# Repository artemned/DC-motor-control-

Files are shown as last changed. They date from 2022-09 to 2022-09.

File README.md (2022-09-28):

# DC-motor-control
### *Hello everyone, I want to share with you my device. This is a DC motor control board. The board is multifunctional and you can verify this by looking at the circuit diagram and the software part. This functionality can be added as needed: connecting sensors, necessary peripherals and adding the software part.*
## *The board looks like :* 
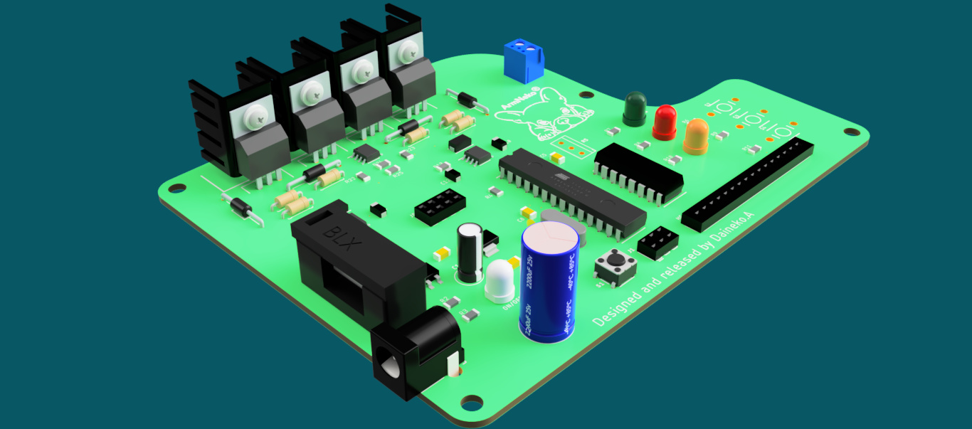
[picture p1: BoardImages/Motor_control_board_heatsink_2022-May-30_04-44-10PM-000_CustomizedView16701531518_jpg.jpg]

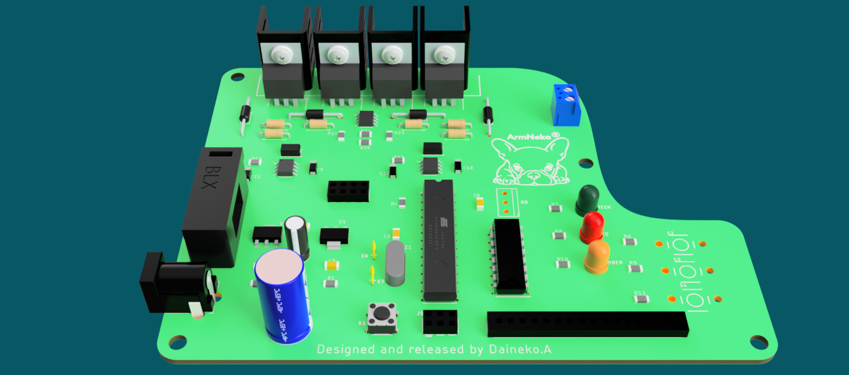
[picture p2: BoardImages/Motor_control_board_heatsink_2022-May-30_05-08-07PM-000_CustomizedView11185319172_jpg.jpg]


### *In the “DriverBoardCode” directory, in addition to the sources and the hex file of the firmware, there is also a zip file of the project, which was created using Microchip Studio.*

### *I use it for my own wood lathe, which is shown in the render in the “BoardImages” directory. The machine is called "Eaglet".*
## *The Eaglet looks like :*
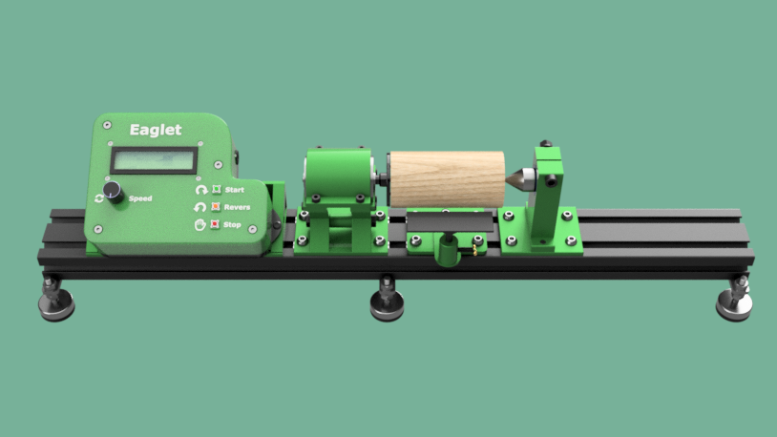
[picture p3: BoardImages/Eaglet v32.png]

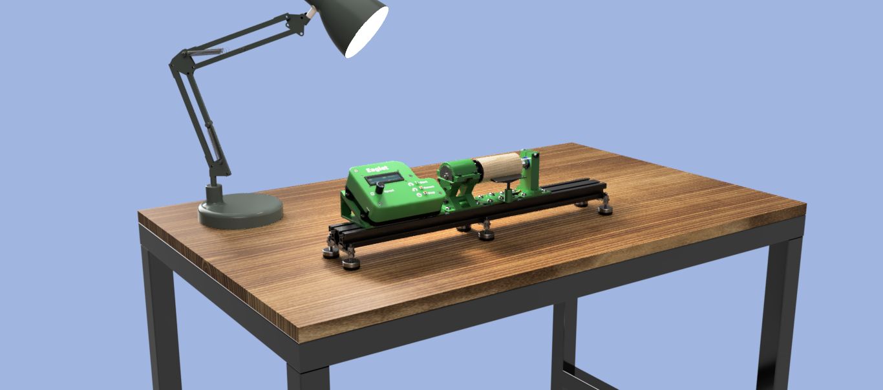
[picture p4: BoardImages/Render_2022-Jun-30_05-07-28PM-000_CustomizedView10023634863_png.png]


### *P.S. Everyone goodness and fresh cookies!*
### *License: [Free license](https://github.com/artemned/DC-motor-control-/blob/main/LICENSE)*
### *Email address for feedback: daineko.a32@mail.ru*

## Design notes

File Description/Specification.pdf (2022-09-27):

Qty | Value | Device | Package | Parts | Description
4 | | LED-3MM-NO_SILK | LED3MM-NS | AMBER, GREEN, ON/OFF, RED | LEDs
1 | 1.0uF | CPOL-EUE2,5-6E | E2,5-6E | C1 | POLARIZED CAPACITOR, European symbol
2 | 3.7uF | CPOL-USSMCA | SMC_A | C11, C12 | POLARIZED CAPACITOR, American symbol
2 | 10uF | C-EUC1206 | C1206 | C2, C3 | CAPACITOR, European symbol
1 | 2200uF | CPOL-EUE5-10.5 | E5-10,5 | C4 | POLARIZED CAPACITOR, European symbol
1 | 10nF | C-EUC1206 | C1206 | C5 | CAPACITOR, European symbol
2 | 22pF | 22PF-PTH-2.54MM-200V-5% | CAP-PTH-2.54 | C6, C7 | 22pF ceramic capacitors
1 | 0.1uF | C-EUC1206 | C1206 | C8,C13 | CAPACITOR, European symbol
2 | 370nF | CPOL-USSMCA | SMC_A | C9, C10 | POLARIZED CAPACITOR, American symbol
2 | MURA110T3G | MURA110T3G | DIOM5226X220N | D1, D2 | Source: Datasheet
4 | MBR0530T1G | MBR0530T1G | SOD3716X135N | D3, D5, D7, D9 | Schottky Rectifier 0.5A 30V SOD-123 ON Semiconductor MBR0530T1G Schottky Diode, 0.5A, 30V, 2-Pin SOD-123
4 | | 1N4007E-E3_73 | DIOAD1405W86L465D235 | D4, D6, D8, D10 | Rectifiers 1.0 Amp 1000 Volt
1 | | SHK20L | SHK20L | F1 | FUSE HOLDER 5 x 20 mm, SH contact, SHH1 Schukat, E1073 Buerklin
1 | LCD16X2 | LCD16X2 | 1X16 | HG1 | LCD 16X2
1 | | ATMEGA328P-PU | DIP794W53P254L3467H457Q28N | IC1 | MICROCHIP - ATMEGA328P-PU. - MICROCONTROLLER MCU, 8 BIT, ATMEGA, 20MHZ, DIP-28
1 | SN74HC595N | SN74HC595N | DIP794W53P254L1930H508Q16N | IC2 | 8-Bit Shift Registers With 3-State Output Registers
2 | IR2101SPBF | IR2101SPBF | SOIC127P600X175-8N | IC3, IC4 | Gate Drivers HI LO SIDE DRVR 600V 130mA 50ns
1 | OPA2376AIDRG4 | OPA2376AIDRG4 | SOIC127P600X175-8N | IC5 | Precision Amplifiers Prec Lo Noise Lo Quies Current Op Amp
1 | | AVR_SPI_PROG_3X2PTH | 2X3 | J1 | AVR ISP 6 Pin
1 | POWER_JACKPTH | POWER_JACKPTH | POWER_JACK_PTH | J2 | Power Jack
1 | | PINHD-2X4 | 2X04 | JP1 | PIN HEADER
1 | DC 24 | Motor | 775 Model | M1 | Motor Spindel
4 | IRFZ34NPBF | IRFZ34NPBF | TO254P469X1042X1967-3P | Q1, Q2, Q3, Q4 | N-channel MOSFET,IRFZ34N 26A 55V
1 | 16MHZ | XTAL/S | QS | QZ1 | CRYSTAL
1 | 200 | R-US_R1206 | R1206 | R1 | RESISTOR, American symbol
2 | 10 | R-US_R1206 | R1206 | R12, R13 | RESISTOR, American symbol
4 | 2 | R-US_0207/7 | 0207/7 | R14, R15, R18, R19 | RESISTOR, American symbol
2 | 50 | R-US_0207/7 | 0207/7 | R16, R17 | RESISTOR, American symbol
1 | 240 | R-US_R1206 | R1206 | R2 | RESISTOR, American symbol
2 | 0,01 | R-EU_R2512 | R2512 | R20, R21 | RESISTOR, European symbol. Yago 0R01 10 mOm
2 | 10 Mom | R-US_R1206 | R1206 | R22, R23 | RESISTOR, American symbol
2 | 95-100 kOm | R-US_R1206 | R1206 | R24, R25 | RESISTOR, American symbol
1 | 11,7 | R-US_R1205 | R1205 | R26 | RESISTOR, American symbol
1 | 2,2khom | R-US_R1206 | R1206 | R3 | RESISTOR, American symbol
1 | 30k | R-US_R1206 | R1206 | R4 | RESISTOR, American symbol
1 | TRIMM_POT | TRIMM_POT | TRIMM_POT | R5
3 | 100 | R-US_R1206 | R1206 | R6, R9, R11 | RESISTOR, American symbol
3 | 220 | R-US_R1206 | R1206 | R7, R8, R10 | RESISTOR, American symbol
1 | SWITCH | MOMENTARY-SWITCH-6.0MM | TACTILE_SWITCH_PTH_6.0MM | S1 | Momentary Switch (Pushbutton) - SPST
3 | | TAC_SWITCH_SPECIAL | TACTILE-SPECIAL_PTH | S2, S3, S4 | Tac Switch
1 | V_REG_317SMD | V_REG_317SMD | SOT223 | U | Voltage Regulator
1 | LM1117GS-5.0 | V_REG_LM1117SOT223 | SOT223 | U1 | Voltage Regulator LM1117
1 | DG340MY" | DG340MY" | 1X02_3.81_SCREWTERM | X1
1 | BZV55C3V6-TP | BAQ33GS08 | smd(mils) | Z | Zener Diodes 3.3V 0.152A
Resistors 22,23,24,25 can be selected deoending on the motor model

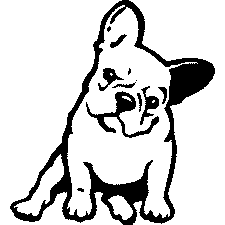
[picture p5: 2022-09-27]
Driver_motor/french`s/franchF.bmp

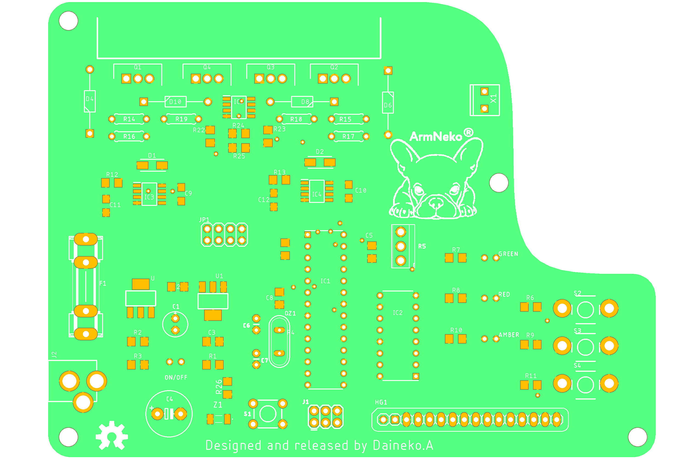
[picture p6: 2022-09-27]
Description/board_top.png

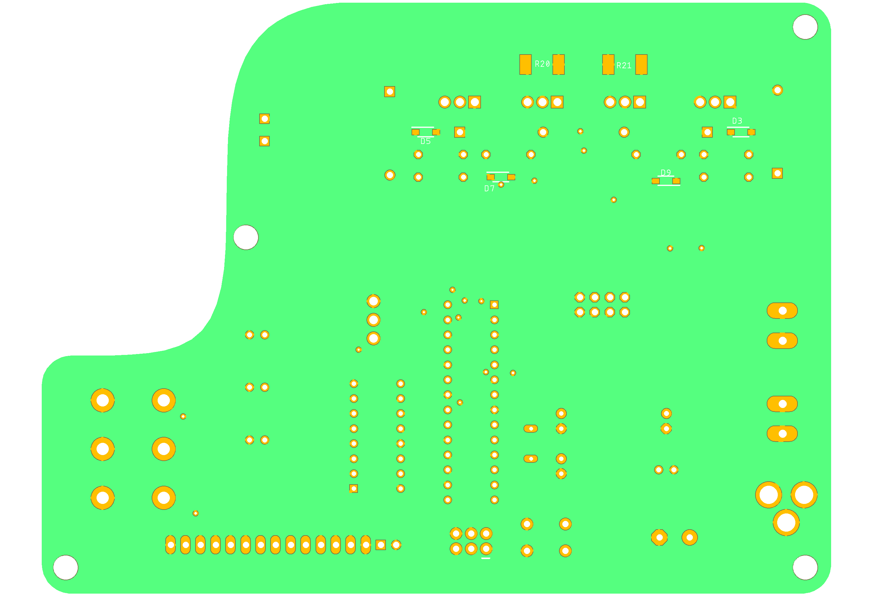
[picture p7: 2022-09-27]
Description/board_bottom.png

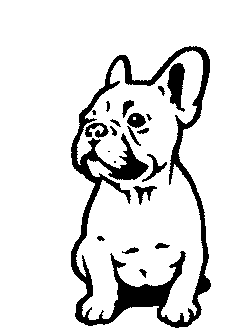
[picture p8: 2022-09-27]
Driver_motor/french`s/franchS.bmp

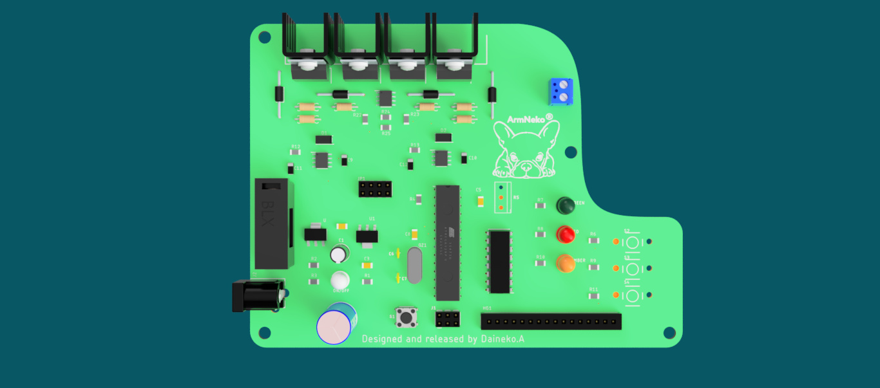
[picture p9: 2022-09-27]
BoardImages/Motor_control_board_heatsink_2022-May-30_05-16-09PM-000_CustomizedView3325845556_jpg.jpg

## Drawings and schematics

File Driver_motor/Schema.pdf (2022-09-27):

A

A

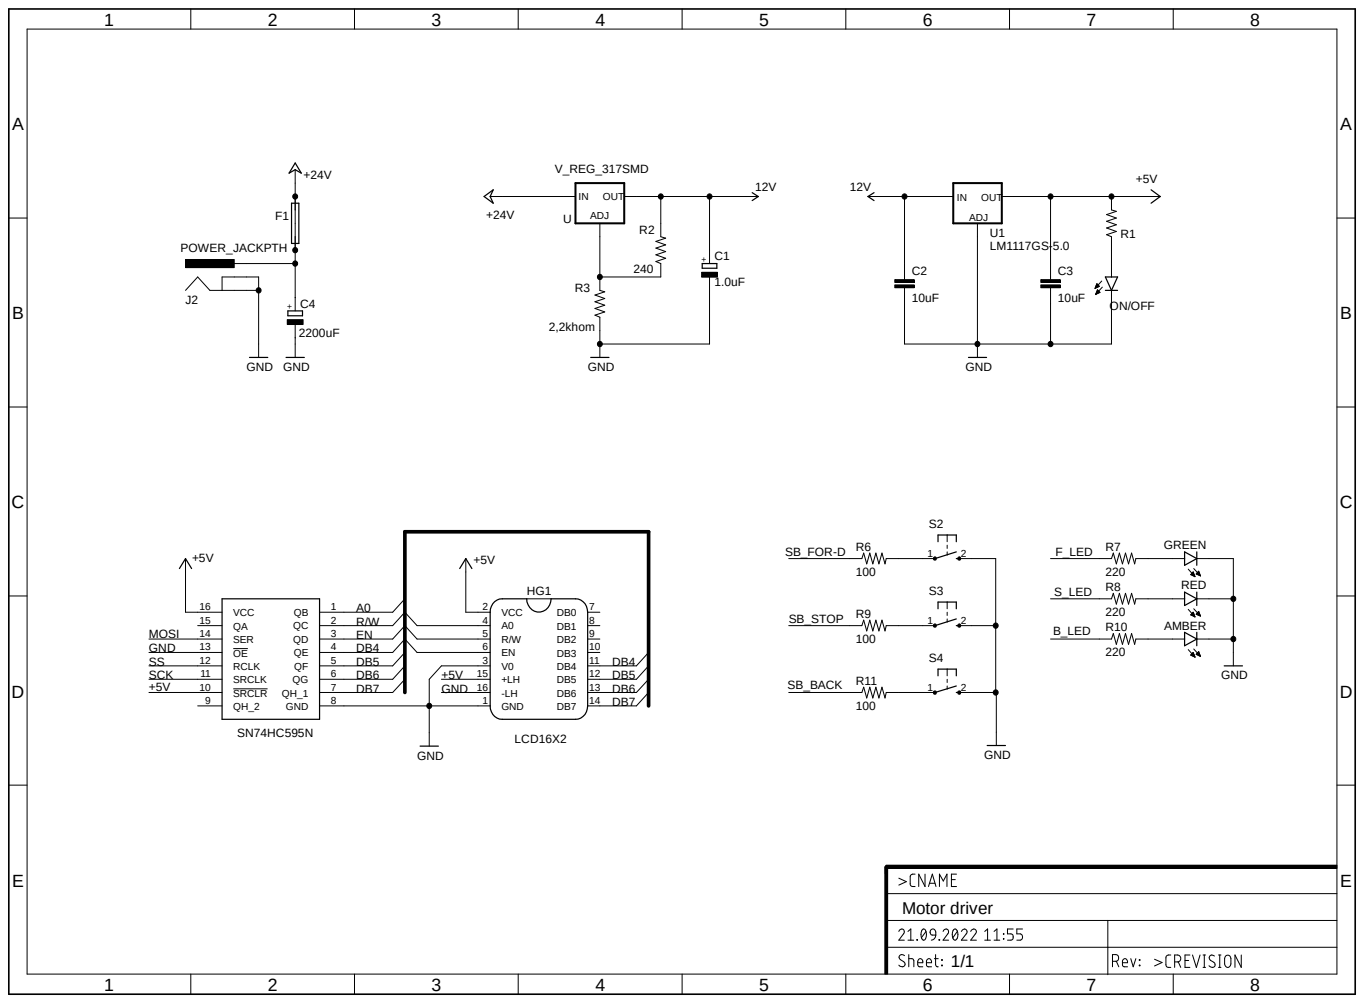
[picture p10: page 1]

5 | 6 | C5

A

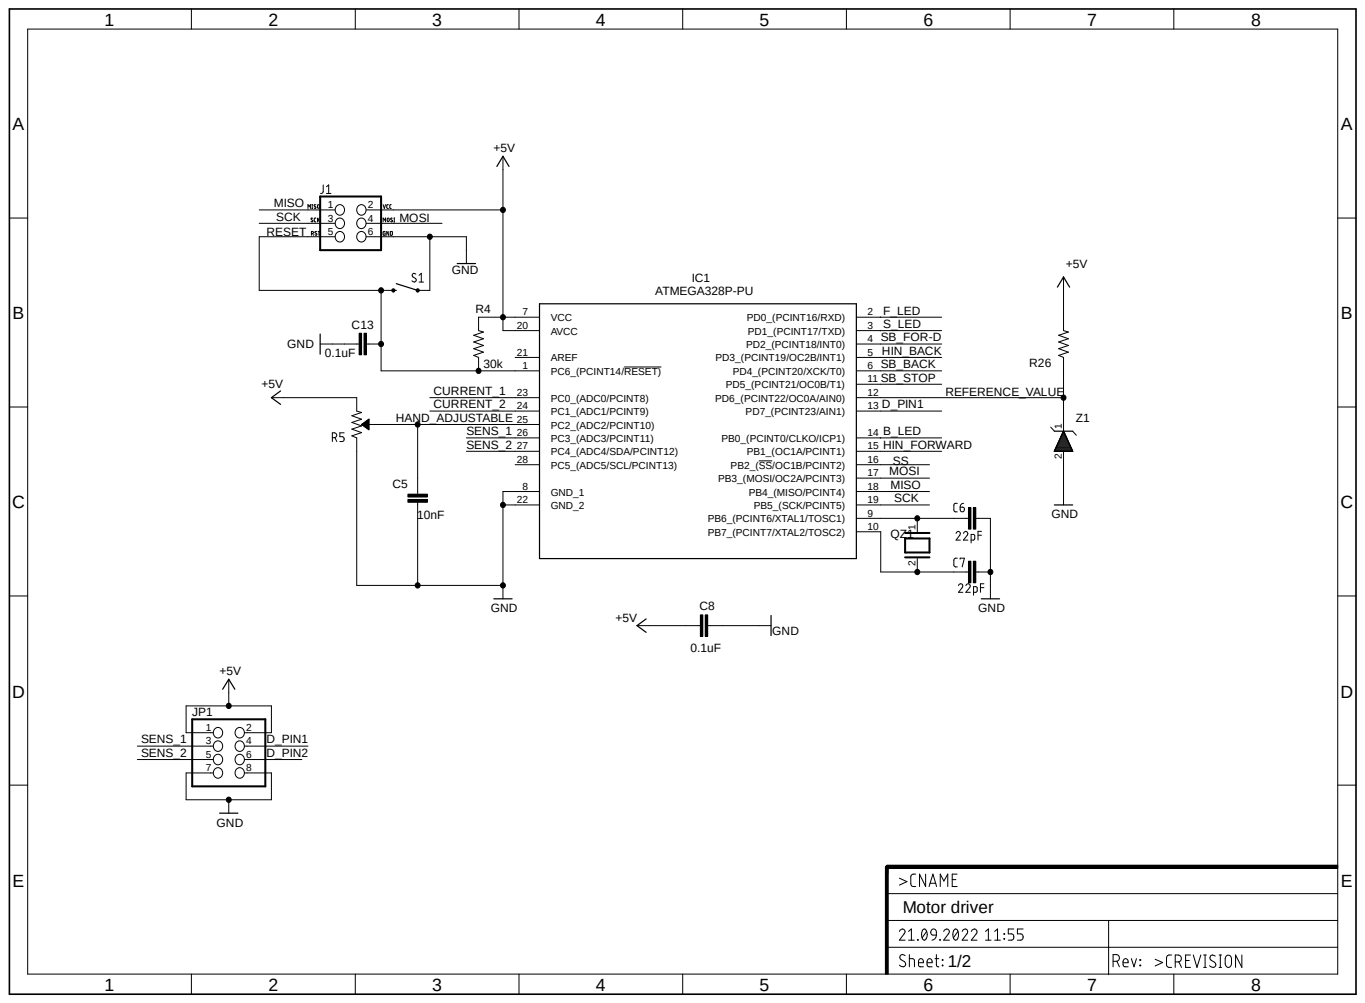
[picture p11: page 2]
GND; ATMEGA328P-PU; PC6_(PCINT14/RESET) 1; PD0_(PCINT16/RXD); PD1_(PCINT17/TXD); PD2_(PCINT18/INT0); PD3_(PCINT19/OC2B/INT1); PD4_(PCINT20/XCK/T0); VCC 7; GND_1 8; PB6_(PCINT6/XTAL1/TOSC1); PB7_(PCINT7/XTAL2/TOSC2); PD5_(PCINT21/OC0B/T1); PD6_(PCINT22/OC0A/AIN0); PD7_(PCINT23/AIN1); PB0_(PCINT0/CLKO/ICP1); PB1_(OC1A/PCINT1); PB2_(SS/OC1B/PCINT2); PB3_(MOSI/OC2A/PCINT3); PB4_(MISO/PCINT4); PB5_(SCK/PCINT5); AVCC 20; AREF 21; GND_2 22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

A

A

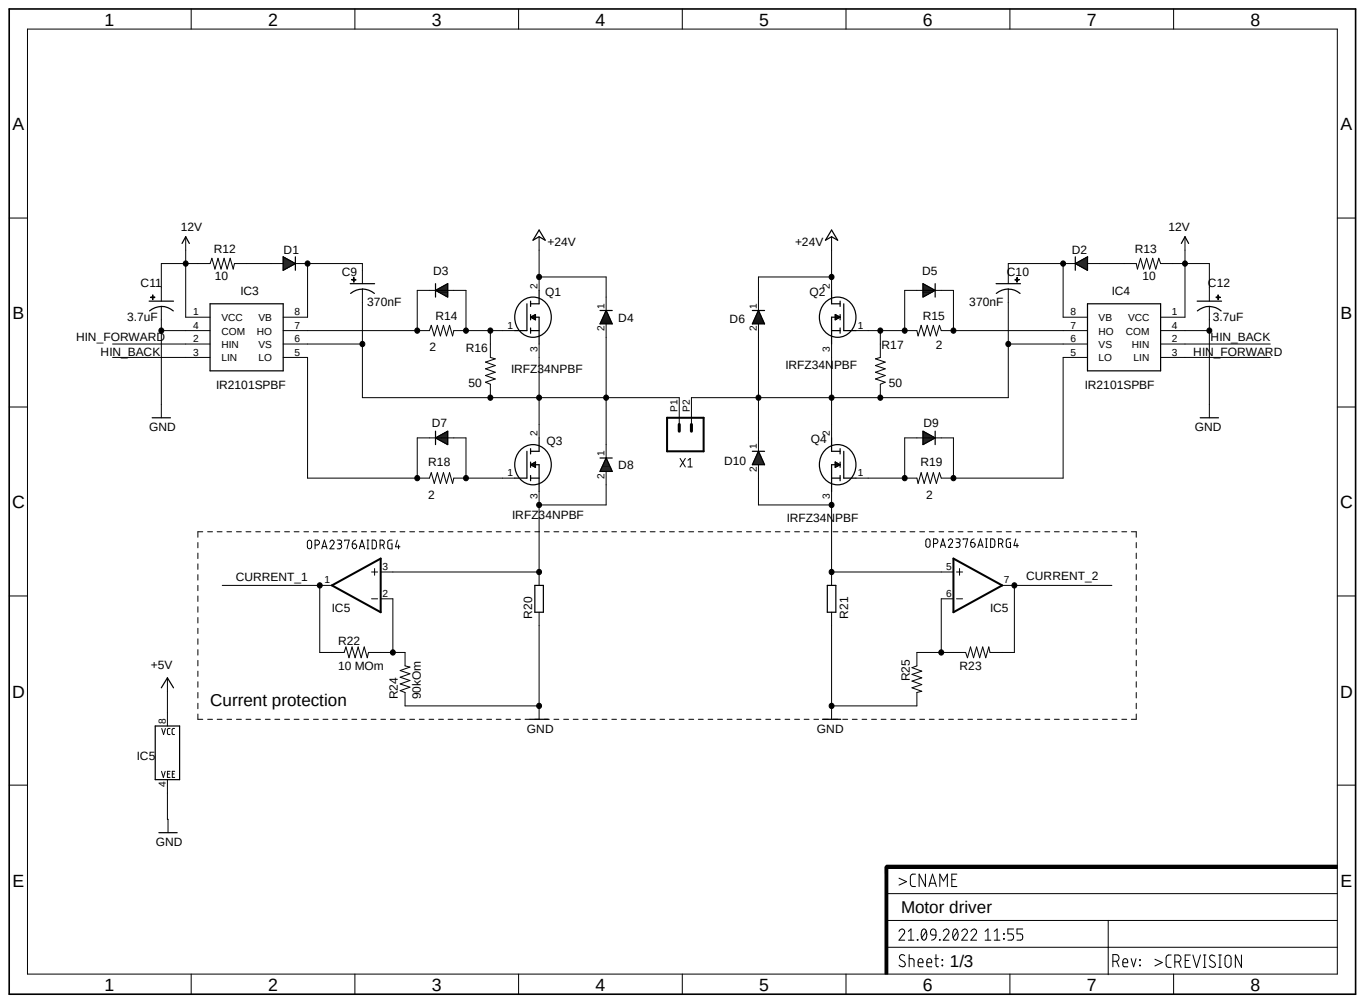
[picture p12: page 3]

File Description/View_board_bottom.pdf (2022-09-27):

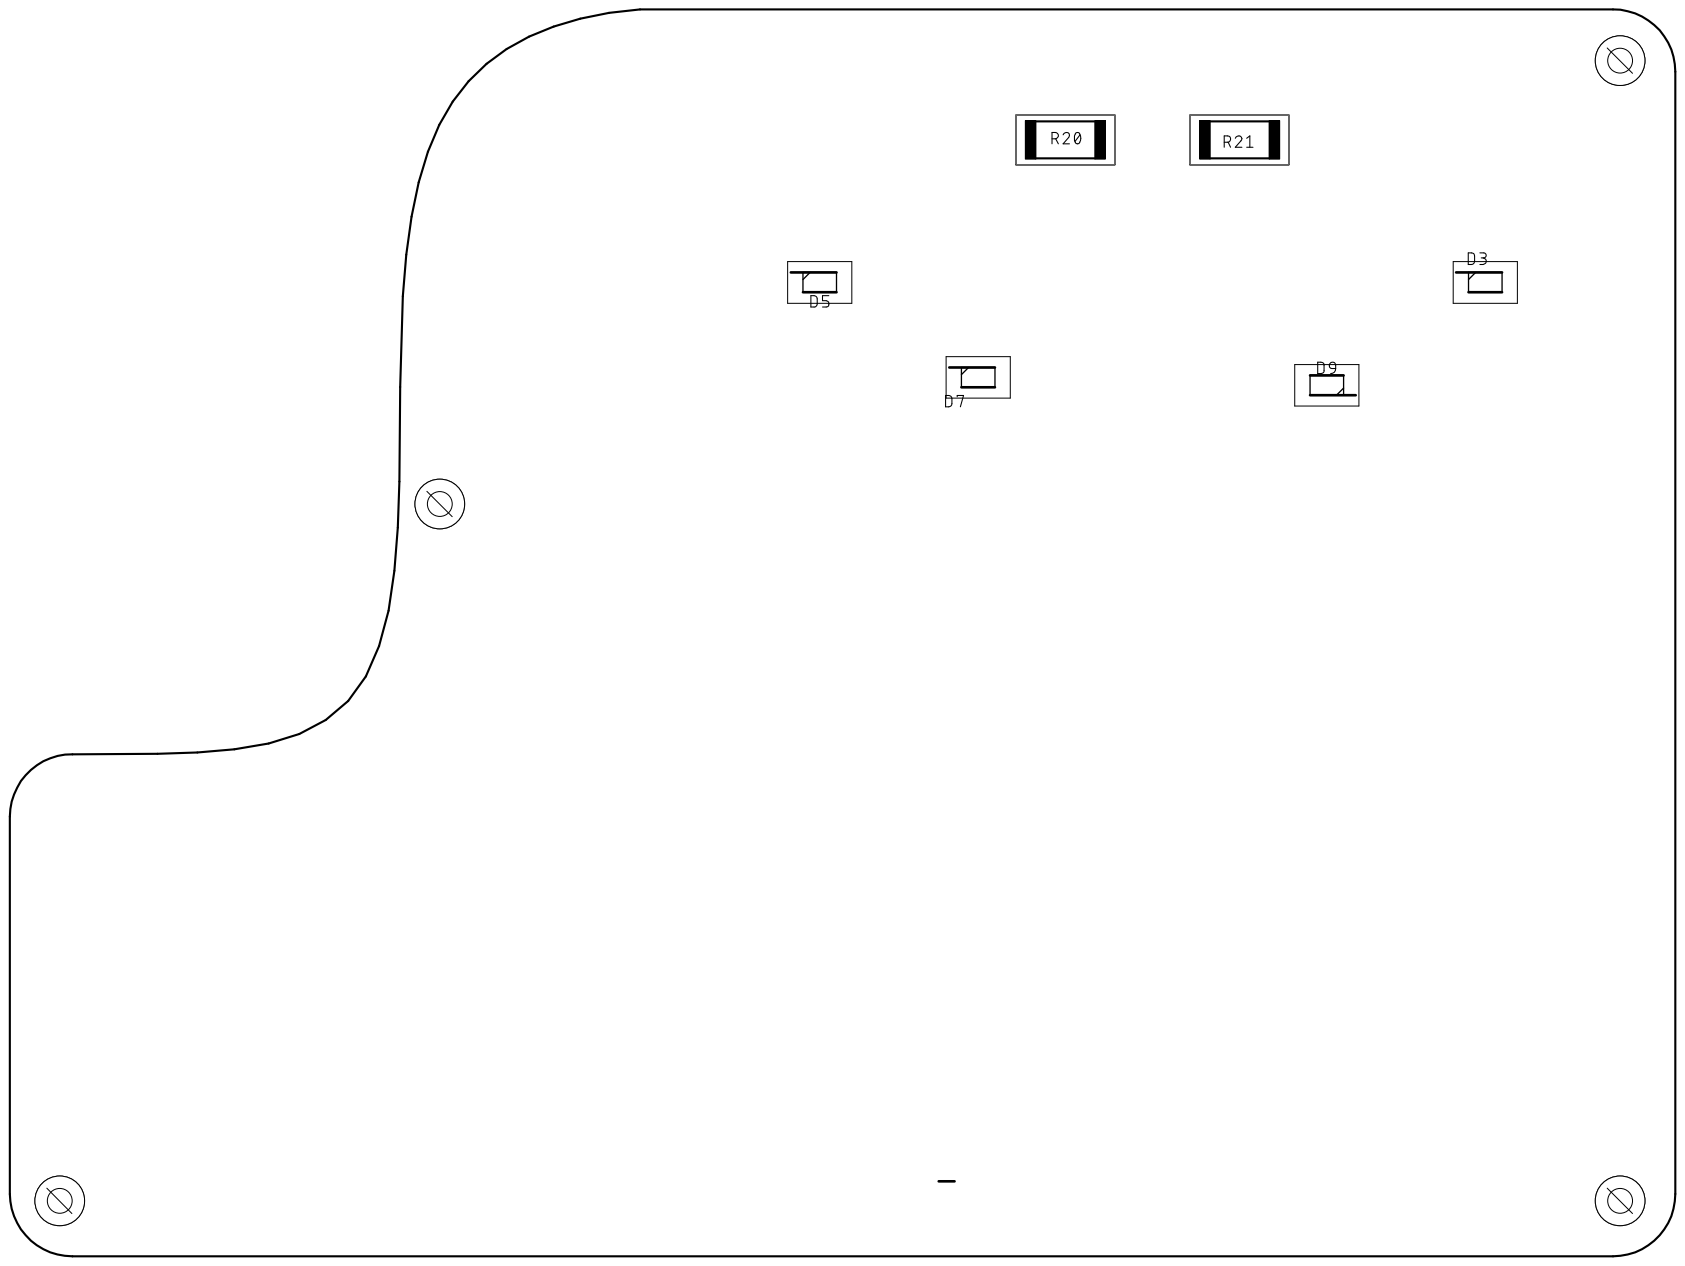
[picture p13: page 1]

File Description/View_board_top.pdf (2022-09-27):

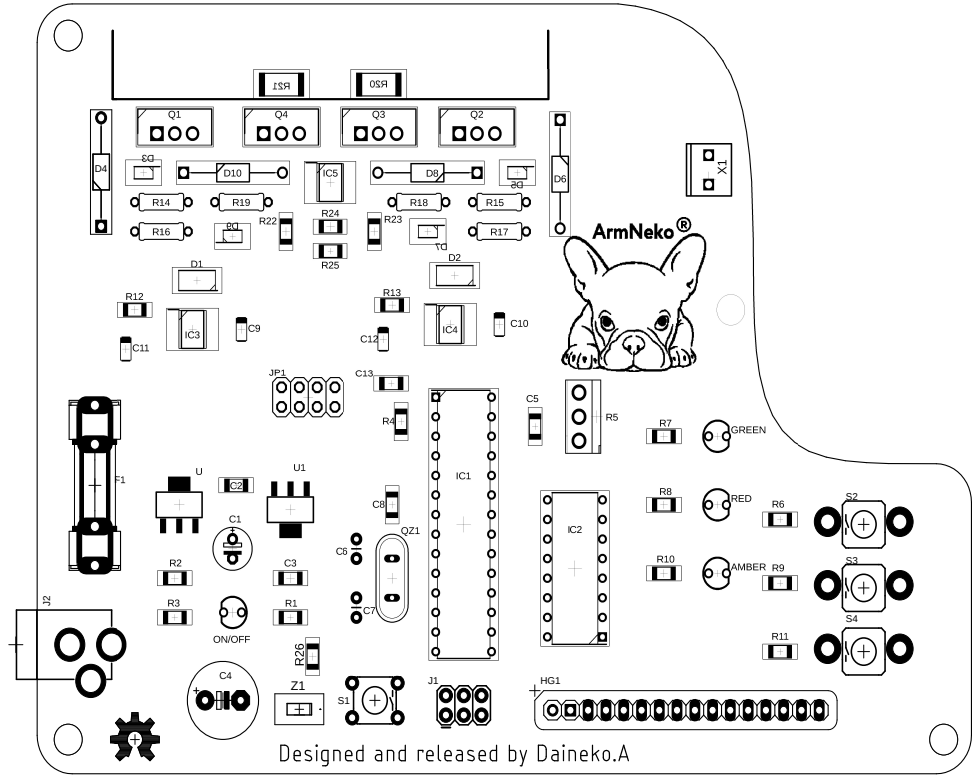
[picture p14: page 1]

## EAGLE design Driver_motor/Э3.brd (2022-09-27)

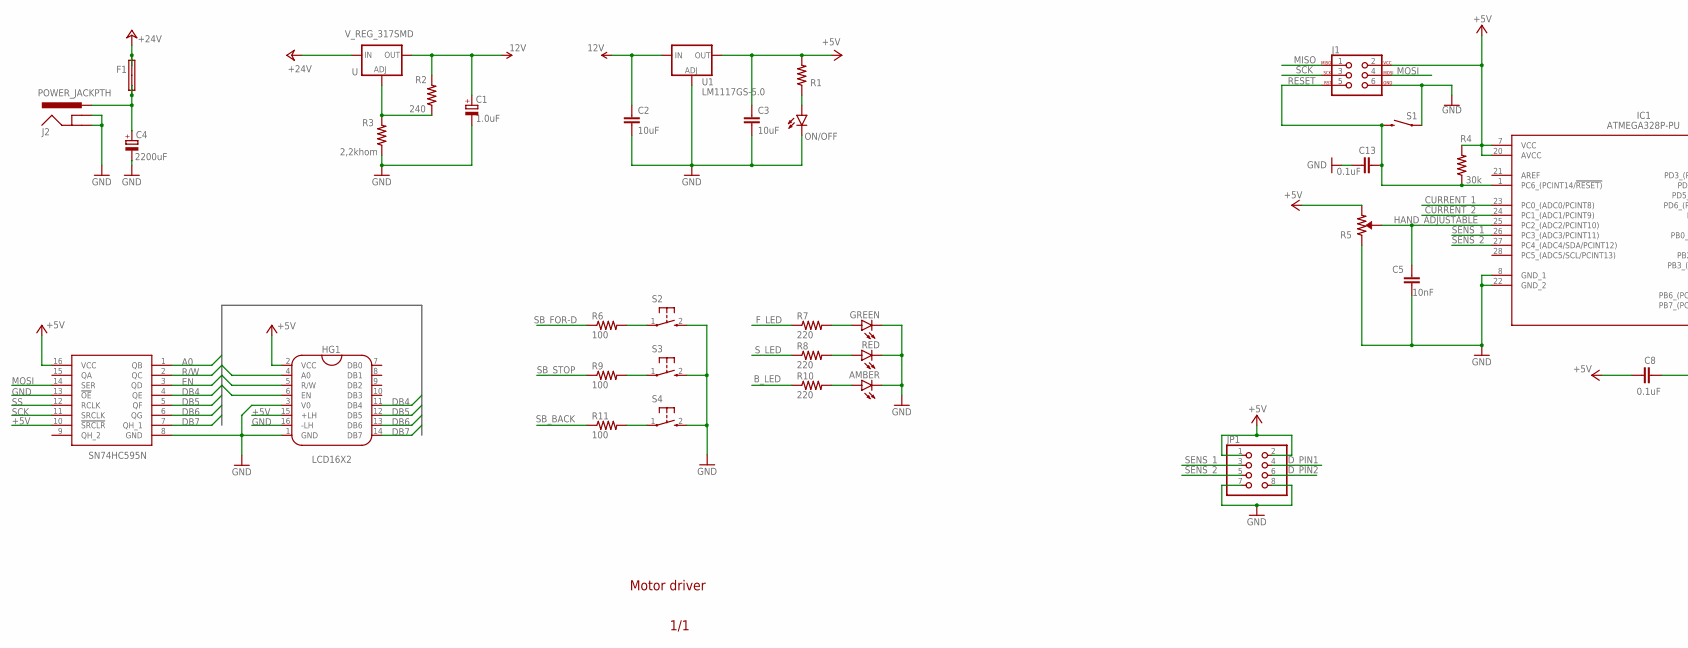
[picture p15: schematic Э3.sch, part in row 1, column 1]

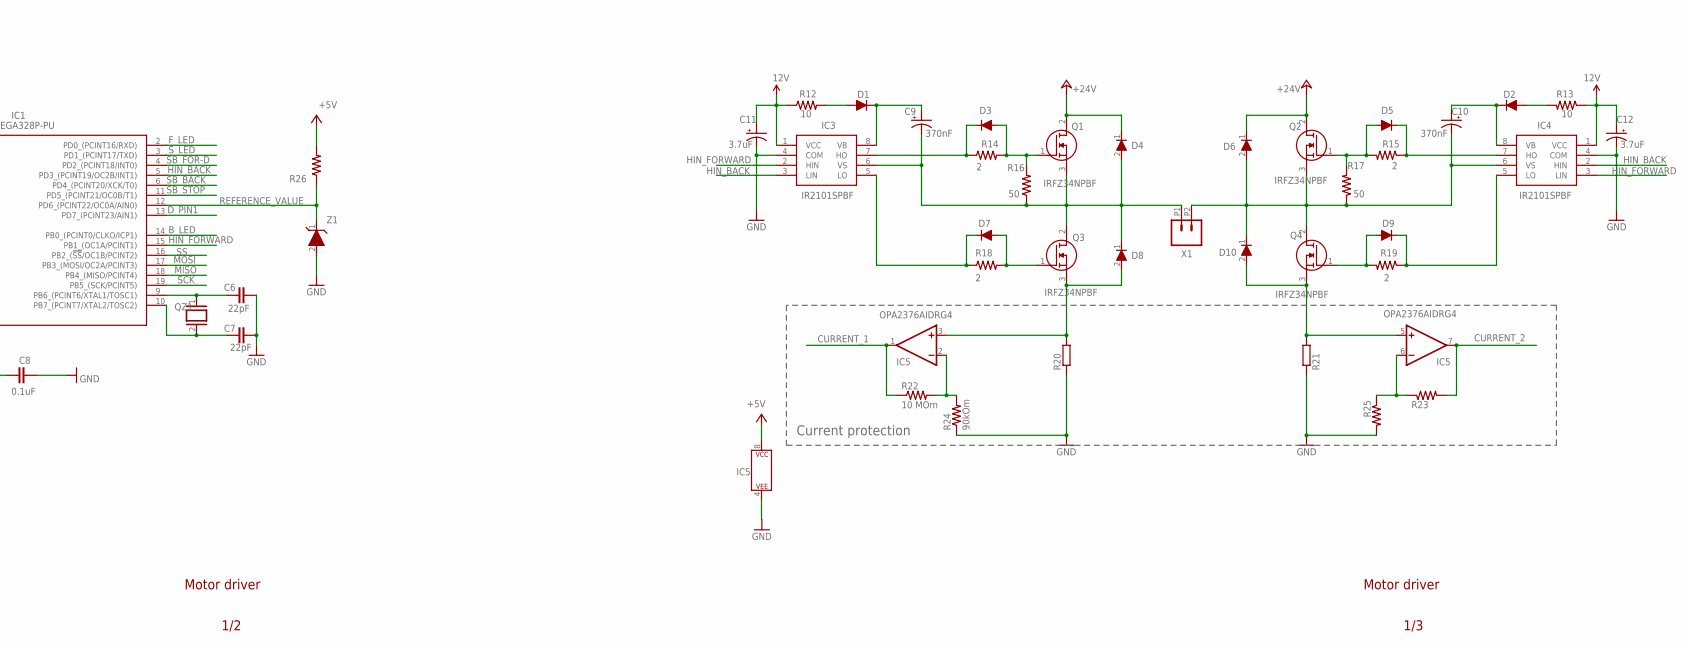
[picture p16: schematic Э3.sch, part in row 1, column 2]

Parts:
AMBER: LED-3MM-NO_SILK; LED3MM-NS
C1: 1.0uF; E2,5-6E
C2, C3: 10uF; C1206
C4: 2200uF; E5-10,5
C5: 10nF; C1206
C6, C7: 22pF; CAP-PTH-2.54
C8, C13: 0.1uF; C1206
C9, C10: 370nF; SMC_A
C11, C12: 3.7uF; SMC_A
D1, D2: MURA110T3G; DIOM5226X220N
D3, D5, D7, D9: MBR0530T1G; SOD3716X135N
D4, D6, D8, D10: 1N4007E-E3_73; DIOAD1405W86L465D235
F1: SHK20L
GREEN: LED-3MM-NO_SILK; LED3MM-NS
HG1: LCD16X2; 1X16
IC1: ATMEGA328P-PU; DIP794W53P254L3467H457Q28N
IC2: SN74HC595N; DIP794W53P254L1930H508Q16N
IC3, IC4: IR2101SPBF; SOIC127P600X175-8N
IC5: OPA2376AIDRG4; SOIC127P600X175-8N
J1: AVR_SPI_PROG_3X2PTH; 2X3
J2: POWER_JACKPTH; POWER_JACK_PTH
JP1: PINHD-2X4; 2X04
ON/OFF: LED-3MM-NO_SILK; LED3MM-NS
Q1, Q2, Q3, Q4: IRFZ34NPBF; TO254P469X1042X1967-3P
QZ1: XTAL/S; QS
R1: 200; R1206
R2: 240; R1206
R3: 2,2khom; R1206
R4: 30k; R1206
R5: TRIMM_POT
R6, R9, R11: 100; R1206
R7, R8, R10: 220; R1206
R12, R13: 10; R1206
R14, R15, R18, R19: 2; 0207/7
R16, R17: 50; 0207/7
R20, R21: R-EU_R2512; R2512
R22: 10 MOm; R1206
R23, R25: R-US_R1206; R1206
R24: 90kOm; R1206
R26: 7; R1206
RED: LED-3MM-NO_SILK; LED3MM-NS
S1: MOMENTARY-SWITCH-SPST-PTH-6.0MM; TACTILE_SWITCH_PTH_6.0MM
S2, S3, S4: TAC_SWITCH_SPECIAL; TACTILE-SPECIAL_PTH
U: V_REG_317SMD; SOT223
U1: LM1117GS-5.0; SOT223
X1: DG340MY""; 1X02_3.81_SCREWTERM
Z1: BZV55C3V6-TP"""; BAQ33GS08

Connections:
12V: C1.+, C2.1, C11.+, C12.+, IC3.1 (VCC), IC4.1 (VCC), R2.2, R12.1, R13.1, U.2 (OUT), U1.3 (IN)
+5V: C3.1, C8.1, HG1.2 (VCC), HG1.15 (+LH), IC1.7 (VCC), IC1.20 (AVCC), IC2.10 (!SRCLR), IC2.16 (VCC), IC5.8 (P$V+), J1.2, JP1.1, JP1.2, R1.2, R4.2, R5.1 (CCW), R26.2, U1.2 (OUT), U1.4 (OUT)
+24V: D4.1 (K), D6.1 (K), F1.2A, F1.2B, Q1.2 (D), Q2.2 (D), U.3 (IN)
A0: HG1.4 (A0), IC2.1 (QB)
B_LED: IC1.14 (PB0_(PCINT0/CLKO/ICP1)), R10.1
CURRENT_1: IC1.23 (PC0_(ADC0/PCINT8)), IC5.1 (OUT), R22.1
CURRENT_2: IC1.24 (PC1_(ADC1/PCINT9)), IC5.7 (OUT), R23.2
DB4: HG1.11 (DB4), IC2.4 (QE)
DB5: HG1.12 (DB5), IC2.5 (QF)
DB6: HG1.13 (DB6), IC2.6 (QG)
DB7: HG1.14 (DB7), IC2.7 (QH_1)
D_PIN1: IC1.13 (PD7_(PCINT23/AIN1)), JP1.4
D_PIN2: JP1.6
EN: HG1.6 (EN), IC2.3 (QD)
F_LED: IC1.2 (PD0_(PCINT16/RXD)), R7.1
GND: AMBER.K (C), C1.-, C2.2, C3.2, C4.-, C5.2, C6.2, C7.2, C8.2, C11.-, C12.-, C13.2, GREEN.K (C), HG1.1 (GND), HG1.3 (V0), HG1.16 (-LH), IC1.8 (GND_1), IC1.22 (GND_2), IC2.8 (GND), IC2.13 (!OE), IC3.4 (COM), IC4.4 (COM), IC5.4 (P$V-), J1.6, J2.GND, J2.GNDBREAK, JP1.7, JP1.8, ON/OFF.K (C), R3.1, R5.3 (CW), R20.1, R21.1, R24.1, R25.2, RED.K (C), S1.1, S2.2 (3), S3.2 (3), S4.2 (3), U1.1 (ADJ), Z1.2 (A)
HAND_ADJUSTABLE: C5.1, IC1.25 (PC2_(ADC2/PCINT10)), R5.2 (WIPER)
HIN_BACK: IC1.5 (PD3_(PCINT19/OC2B/INT1)), IC3.3 (LIN), IC4.2 (HIN)
HIN_FORWARD: IC1.15 (PB1_(OC1A/PCINT1)), IC3.2 (HIN), IC4.3 (LIN)
MISO: IC1.18 (PB4_(MISO/PCINT4)), J1.1
MOSI: IC1.17 (PB3_(MOSI/OC2A/PCINT3)), IC2.14 (SER), J1.4
unnamed: ON/OFF.A, R1.1
unnamed: C4.+, F1.1A, F1.1B, J2.PWR
unnamed: D8.2 (A), IC5.3 (+IN), Q3.3 (S), R20.2
unnamed: D10.2 (A), IC5.5 (+IN), Q4.3 (S), R21.2
unnamed: GREEN.A, R7.2
unnamed: R8.2, RED.A
unnamed: AMBER.A, R10.2
unnamed: R2.1, R3.2, U.1 (ADJ)
unnamed: R6.2, S2.1
unnamed: R9.2, S3.1
unnamed: R11.2, S4.1
unnamed: C6.1, IC1.9 (PB6_(PCINT6/XTAL1/TOSC1)), QZ1.1
unnamed: C10.+, D2.1 (K), IC4.8 (VB)
unnamed: C7.1, IC1.10 (PB7_(PCINT7/XTAL2/TOSC2)), QZ1.2
unnamed: C9.+, D1.1 (K), IC3.8 (VB)
unnamed: IC5.2 (-IN), R22.2, R24.2
unnamed: C9.-, D4.2 (A), D8.1 (K), IC3.6 (VS), Q1.3 (S), Q3.2 (D), R16.1, X1.P1 (1)
unnamed: IC5.6 (-IN), R23.1, R25.1
unnamed: D1.2 (A), R12.2
unnamed: D3.1 (K), IC3.7 (HO), R14.1
unnamed: D3.2 (A), Q1.1 (G), R14.2, R16.2
unnamed: D7.2 (A), Q3.1 (G), R18.2
unnamed: D7.1 (K), IC3.5 (LO), R18.1
unnamed: D2.2 (A), R13.2
unnamed: C10.-, D6.2 (A), D10.1 (K), IC4.6 (VS), Q2.3 (S), Q4.2 (D), R17.1, X1.P2 (2)
unnamed: D5.1 (K), IC4.7 (HO), R15.1
unnamed: D5.2 (A), Q2.1 (G), R15.2, R17.2
unnamed: D9.2 (A), Q4.1 (G), R19.2
unnamed: D9.1 (K), IC4.5 (LO), R19.1
R/W: HG1.5 (R/W), IC2.2 (QC)
REFERENCE_VALUE: IC1.12 (PD6_(PCINT22/OC0A/AIN0)), R26.1, Z1.1 (K)
RESET: C13.1, IC1.1 (PC6_(PCINT14/!RESET)), J1.5, R4.1, S1.3 (2)
SB_BACK: IC1.6 (PD4_(PCINT20/XCK/T0)), R11.1
SB_FOR-D: IC1.4 (PD2_(PCINT18/INT0)), R6.1
SB_STOP: IC1.11 (PD5_(PCINT21/OC0B/T1)), R9.1
SCK: IC1.19 (PB5_(SCK/PCINT5)), IC2.11 (SRCLK), J1.3
SENS_1: IC1.26 (PC3_(ADC3/PCINT11)), JP1.3
SENS_2: IC1.27 (PC4_(ADC4/SDA/PCINT12)), JP1.5
SS: IC1.16 (PB2_(!SS!/OC1B/PCINT2)), IC2.12 (RCLK)
S_LED: IC1.3 (PD1_(PCINT17/TXD)), R8.1

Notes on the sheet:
IC5
Current protection
Motor driver
1/3
1/2
1/1

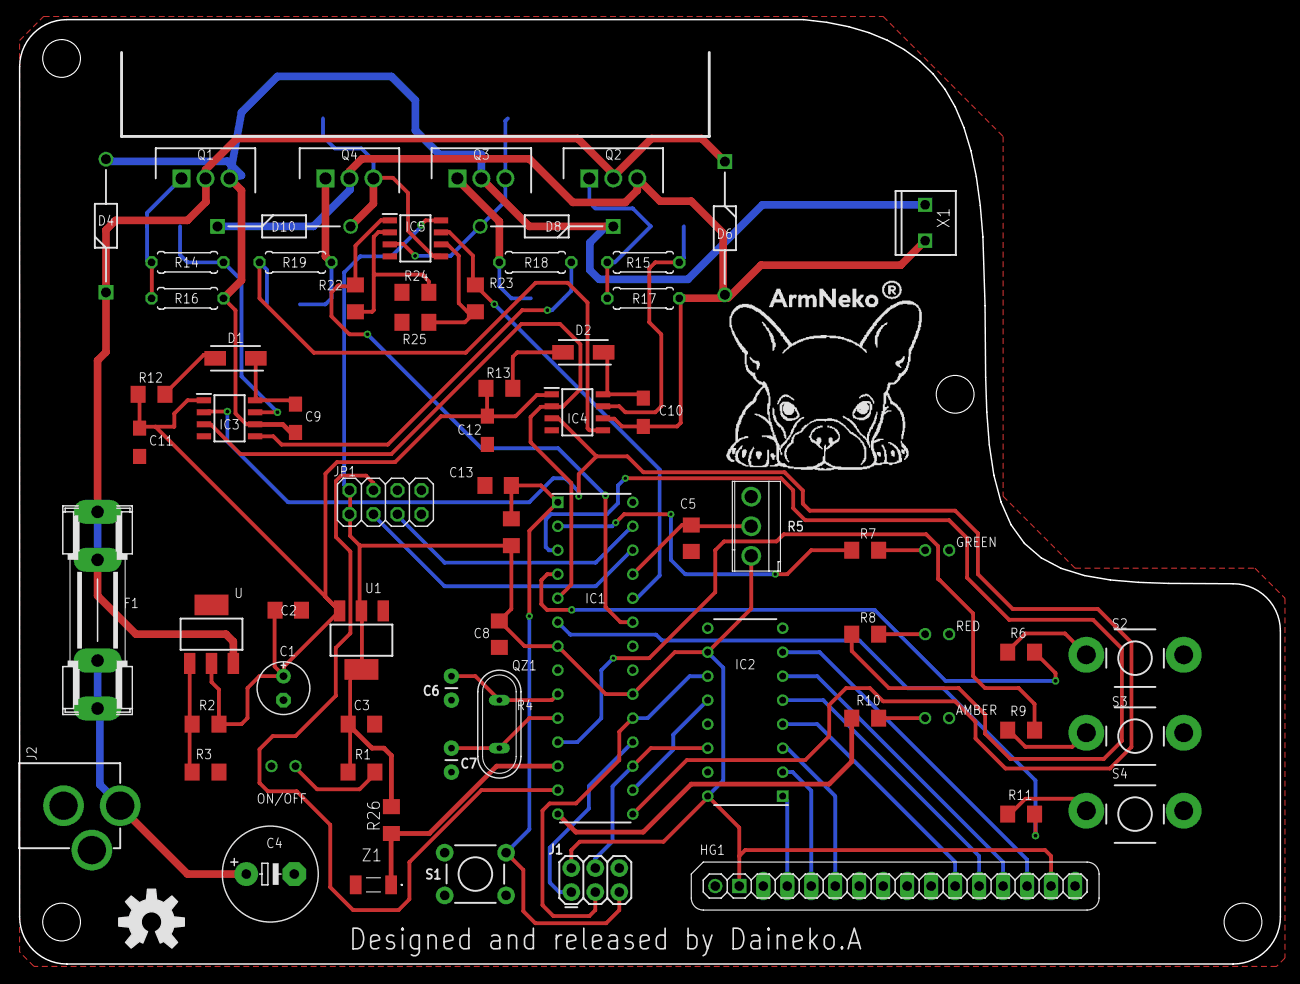
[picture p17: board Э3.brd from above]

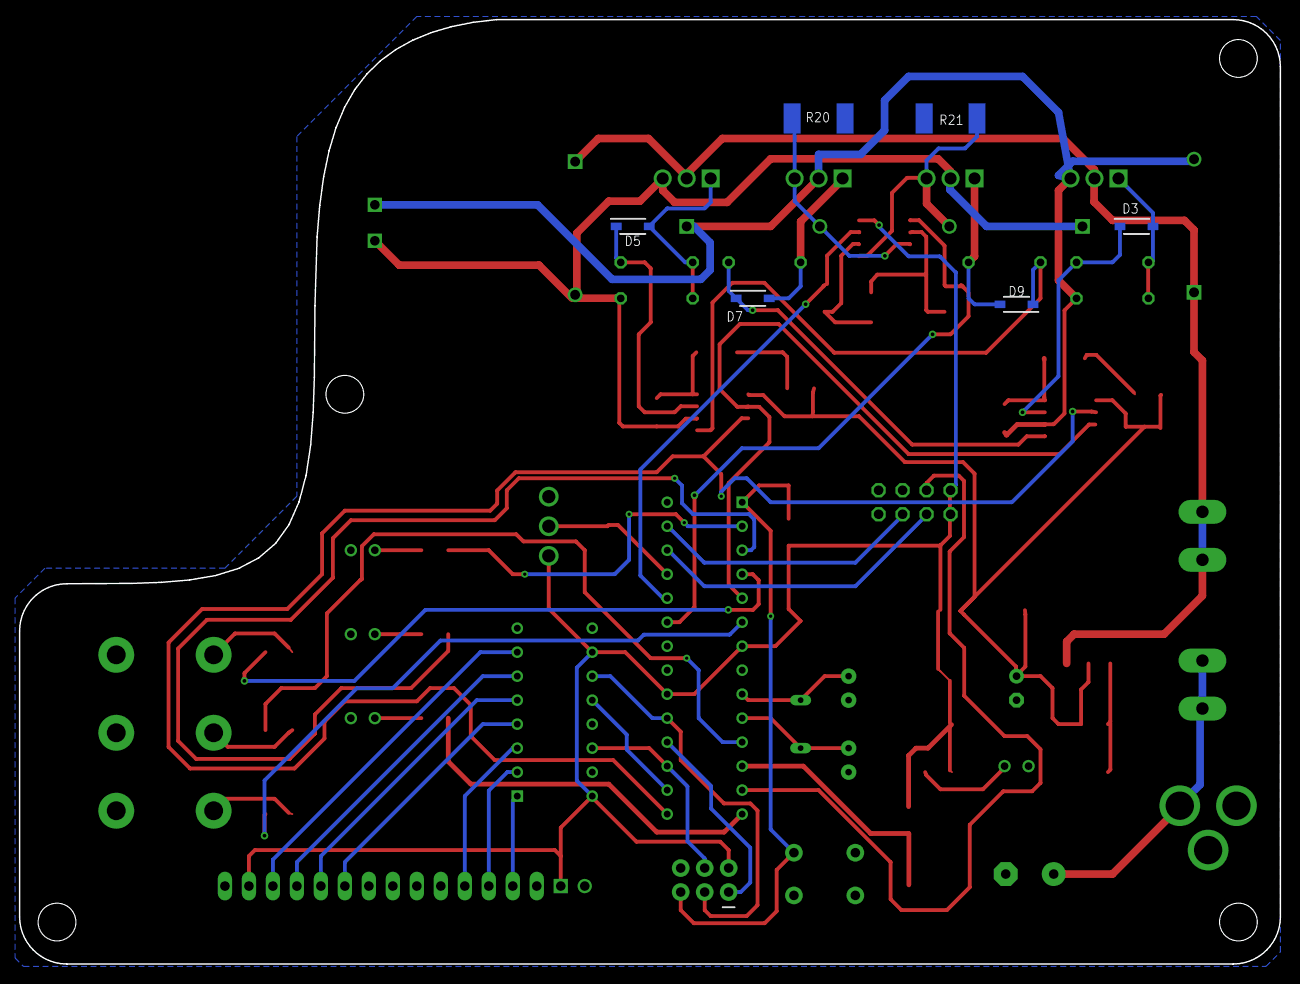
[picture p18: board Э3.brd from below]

Board: 2 copper layers, 133.5 x 100.0 mm, 77 parts (6 on the bottom side), 60 nets.

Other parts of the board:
U$1: OSHW-LOGO-L

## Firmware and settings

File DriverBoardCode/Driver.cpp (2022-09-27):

/*
 * DriverBoard.cpp
 *
 * Created: 30.07.2022 14:01:40
 * Author : ArmNeko
 */ 
#include <Arduino.h>
#include <LiquidCrystalRus.h>
#include "Setup.h"
#include <avr/interrupt.h>



volatile bool start_click=0;//counter up number of occurrences
volatile bool back_click=0;  //counter up number of occurrences
volatile bool stop_click=0; //counter up number of occurrences

volatile bool comparatorState;// Comparator state value
bool oldComparatorState; 

volatile bool startState,backState,stopState; //Button state value
bool oldStartState,oldBackState,oldStopState;

volatile int8_t seconds=0;

LiquidCrystalRus lcd(10);
AnalogToDigitalConverter  adcConverter;
PwmTimer myPWMtimer;

enum Mode{WORK,EMERGENCY,SHORTCIRCUIT}myMode=WORK;

 volatile enum struct Motor
 {
   BACK=0,
   START,
   STOP
 }motor;

ISR(PCINT2_vect)
{ 
	 asm volatile("NOP");
	 
  if(bit_is_clear(READ_PIN_D,SB_FORD))
  {
    startState=true;
    stop_click=false;
    back_click=false;
	  
  }else if(bit_is_clear(READ_PIN_D,SB_STOP))
  {
    stopState=true;
    start_click=false;
    back_click=false;
	
  }else if(bit_is_clear(READ_PIN_D,SB_BACK))
  {
    backState=true;
    start_click=false;
    stop_click=false;
  }
    asm volatile("NOP");      
}

ISR(TIMER1_OVF_vect)
{ 
  TCNT1+=0xC2F6;
  seconds++;
}

ISR(ANALOG_COMP_vect)
{
  ACSR=0x00;
  clear_bit(TCCR1A,COM1A1);
  clear_bit(TCCR2A,COM2B1);
  clear_bit(DIRECTION_PORTS_B,HIN_FORWARD);
  clear_bit(DIRECTION_PORTS_D,HIN_BACK); 
  OCR1A=0;
  OCR2B=0; 
  motor=Motor::STOP;
  bit_is_clear(ANALOG_COMP_STATE_REGISTR,ACI);
  comparatorState = true;     
  myMode=comparatorState ? EMERGENCY : WORK;                 
}


int main(void)
{
  sei();
  setPins();
  setInterrupt();
  motor=Motor::STOP;
 
    while (1) 
    {
/////////////////Press buttons//////////////////////////////   
   
  if(startState)// Button start
 {
   if(oldStartState==0)
   {
    motor=Motor::START;
    oldStartState=true;
    oldStopState=false;
    oldBackState=false;
   }
            
      startState=false;   
 
 }
  else if(stopState)// Button stop
 {
  if(oldStopState==0)
  {
     motor=Motor::STOP;
     oldStopState=true;
     oldStartState=false;
     oldBackState=false;
  }
   stopState=false;
 }
  else if(backState) //Button revers
 {
  if(oldBackState==0)
  {
     motor=Motor::BACK;
     oldBackState=true;
     oldStartState=false;
     oldStopState=false;     
  }
   backState=false;
 }
   
/////////////////////////////////////////////////////////  
   



/////////////////Programm main tread///////////////////////////////////////
        
   switch(myMode)
{

 case EMERGENCY:
 {
   myPWMtimer.pwmOff();
   adcConverter.setOnlyAnalog();
   myPWMtimer.setTimer();
   lcd.setCursor(0,0);
   lcd.print("Аварийный режим!");
   lcd.setCursor(0,1);
   lcd.print("перегрузка...");
   //lcd.print("OverLoad...");
   //lcd.scrollDisplayLeft();
   seconds=0;
   while(seconds!=1){;}; 
   float operatingVoltage = adcConverter.readVoltage(myPWMtimer.pwm_state);
   if(operatingVoltage >= MAXIMUM_VALUE)
   {
     myMode=SHORTCIRCUIT;	 
   }
   else 
   {
	 seconds=0;
	 stop_click=false;
	 start_click=false;
	 back_click=false;
	 oldStartState=false;
	 oldStopState=false;
	 oldBackState=false;
	 while(seconds!=5){;};  
     myMode=WORK;
	 bit_is_clear(ANALOG_COMP_STATE_REGISTR,ACI);
     comparatorState=false;
	 lcd.clear();
     lcd.setCursor(4,0);
     lcd.print("Проверьте");
     lcd.setCursor(4,1);
     lcd.print("шпиндель!");
	 //lcd.setCursor(4,0);
	 //lcd.print("Cheack");
	 //lcd.setCursor(4,1);
	 //lcd.print("spindle!");
	 seconds=0;
	 while(seconds!=5){;};
   }
  
 break;
}
 case SHORTCIRCUIT:
 {

    shutDonw();
    lcd.clear();
    lcd.setCursor(7,0);
    lcd.print("Короткое замыкание...");
	//lcd.print("Short circuit!");
    lcd.setCursor(7,1);
    lcd.print("Устраните причину!");
	//lcd.print("Eliminate the cause!")
    while(1)
    {
   	  _delay_ms(500);
   	  lcd.scrollDisplayLeft();
    }	 
   break;
 }
 case WORK:
 { 
     myPWMtimer.setPwm();
    switch(static_cast<uint8_t>(motor))
   {
         
     case static_cast<uint8_t>(Motor::START):
   {
      if(!start_click)
     {
       myPWMtimer.setState((uint8_t)Motor::START);
       myPWMtimer.pwmOn(comparatorState);
	   adcConverter.pullUpCompPin(myPWMtimer.pwm_state);
       set_bit(CONFIGURATION_PORTS_D,F_LED);
       start_click=true;
       lcd.clear();
       lcd.setCursor(0,0);
       lcd.print("Прямое вращение");
       lcd.setCursor(0,1);
       lcd.print("скорость:");
     //lcd.setCursor(0,0);
     //lcd.print("Forward rotation");
     //lcd.setCursor(2,1);
     //lcd.print("Speed:"); 
     }
     while(start_click)
     {
       lcd.setCursor(9,1);
       adcConverter.setADC(myPWMtimer.pwm_state); 
       lcd.print(adcConverter.procValue);
	   if(adcConverter.procValue < 10)
	   {
		lcd.setCursor(10,1);
		lcd.print("  ");   
	   }
       lcd.setCursor(12,1);
       lcd.print('%');  
       if(comparatorState)break;
     }
     clear_bit(CONFIGURATION_PORTS_D,F_LED);   
     lcd.clear(); 
    break;         
     }
     case static_cast<uint8_t>(Motor::BACK):
   {
     if(!back_click)
     {
      myPWMtimer.setState((uint8_t)Motor::BACK);
      myPWMtimer.pwmOn(comparatorState);
	  adcConverter.pullUpCompPin(myPWMtimer.pwm_state);
      set_bit(CONFIGURATION_PORTS_B,B_LED);
      back_click=true;
      lcd.clear();
      lcd.setCursor(0,0);
      lcd.print("Обратное вращен.");
      lcd.setCursor(0,1);
      lcd.print("скорость:");
      //lcd.setCursor(2,0);
      //lcd.print("Back rotation");
      //lcd.setCursor(2,1);
      //lcd.print("speed:");
     }
     while(back_click)
     {    
      lcd.setCursor(9,1);
      adcConverter.setADC(myPWMtimer.pwm_state);
      lcd.print(adcConverter.procValue);
     if(adcConverter.procValue < 10)
       {
	       lcd.setCursor(10,1);
	       lcd.print("  ");
       }
       lcd.setCursor(12,1);
       lcd.print('%');
      if(comparatorState)break;
     }
     clear_bit(CONFIGURATION_PORTS_B,B_LED);
     lcd.clear();
     break;
     }
     case static_cast<uint8_t>(Motor::STOP):
     {       
    if(!stop_click)
    {
      myPWMtimer.pwmOff(); 
	  adcConverter.setOnlyAnalog();
      set_bit(CONFIGURATION_PORTS_D,S_LED);
      stop_click=true;
      lcd.clear();
      lcd.setCursor(1,0);
      lcd.print("Шпиндель выкл!");
      lcd.setCursor(0,1);
      lcd.print("скорость:");
	  //lcd.print("Spindle off!");
	  //lcd.print("speed:");
    }
    while(stop_click)
    {  
      lcd.setCursor(9,1);
      adcConverter.readOnlyPOt();
      lcd.print(adcConverter.procValue);
      if(adcConverter.procValue < 10)
       {
	       lcd.setCursor(10,1);
	       lcd.print("  ");
       }
       lcd.setCursor(12,1);
       lcd.print('%');
      if(comparatorState)break;
    }
    clear_bit(CONFIGURATION_PORTS_D,S_LED);
    lcd.clear();
      break;
   }
   
    default:break;
         
   }
 }
               
  default:break;
}

}//while

}

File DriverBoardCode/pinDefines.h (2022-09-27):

/********************************************************************
	created:	2022/07/01
	created:	1:7:2022   10:58
	filename: 	C:\Users\sWe\Documents\Atmel Studio\7.0\pinDefines.h
	file path:	C:\Users\sWe\Documents\Atmel Studio\7.0
	file base:	pinDefines
	file ext:	h
	author:		ArtNeko
	
	purpose:	
*********************************************************************/
#pragma once
#include <avr/io.h>
#include "Bit_manip.h"

#define F_LED PD0
#define S_LED PD1
#define B_LED PB0
#define SB_FORD PD2
#define SB_BACK PD4
#define SB_STOP PD5
#define HIN_FORWARD PB1
#define HIN_BACK PD3
#define REF_VALUE PD6
#define D_PIN PD7

#define CURRENT_VALUE_1 PC0
#define CURRENT_VALUE_2 PC1
#define HAND_ADJUSTABLE PC2
#define SENS_1 PC3
#define SENS_2 PC4

#define DIRECTION_PORTS_D DDRD
#define READ_PIN_D PIND
#define CONFIGURATION_PORTS_D PORTD

#define DIRECTION_PORTS_B DDRB
#define READ_PIN_B PINB
#define CONFIGURATION_PORTS_B PORTB 

#define DIRECTION_PORTS_C DDRC
#define READ_PIN_C PINC
#define CONFIGURATION_PORTS_C PORTC

////////////////Analog registrs////////////////////
#define CONTROL_STATE_REGISTER_A ADCSRA
#define CONTROL_STATE_REGISTER_B ADCSRB
#define ANALOG_COMP_STATE_REGISTR ACSR
#define MUX_SELECTION_REGISTER ADMUX
#define DIGITAL_INPUT_DISABLE_0 DIDR0
#define DIGITAL_INPUT_DISABLE_1 DIDR1 
/////////Voltage edge////////////////////////////
#define REFERENCE_VOLTAGE 4.93
#define MAXIMUM_VALUE 3.3

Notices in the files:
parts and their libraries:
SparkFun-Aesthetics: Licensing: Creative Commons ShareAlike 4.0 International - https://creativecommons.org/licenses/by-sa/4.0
